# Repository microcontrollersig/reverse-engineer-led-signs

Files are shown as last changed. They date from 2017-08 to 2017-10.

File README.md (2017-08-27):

# Figuring out how a commerical Led signs work

#### Images
https://github.com/microcontrollersig/reverse-engineer-led-signs/blob/master/images/readme.md

#### LED matrix(5 columns, 7rows, 14-pins)
http://www.kingbrightusa.com/images/catalog/SPEC/TA20-11EWA.pdf

#### 74HC245
http://www.mouser.com/ds/2/149/MM74HC245A-71310.pdf
http://www.ti.com/lit/ds/symlink/sn74hc245.pdf

#### 74HC373
http://www.st.com/content/ccc/resource/technical/document/datasheet/group1/96/71/e4/bd/17/76/4e/c7/CD00000305/files/CD00000305.pdf/jcr:content/translations/en.CD0000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
http://www.ti.com/lit/ds/symlink/cd74hc373.pdf

#### ULN2003A
https://www.onsemi.com/pub/Collateral/MC1413-D.PDF
http://www.tij.co.jp/jp/lit/ds/slrs027o/slrs027o.pdf

#### 74HC237B
http://www.ti.com/lit/ds/symlink/cd74hc237.pdf

# Files in Repository
Main one is **ledmatrixmodule.fzz** . You need to install **Fritzing** to view it (schematic view). If you can't be stuffed, open **ledmatrixmodule_schem.pdf**

# Things Learned
1. Rows in the first half of the board are connected, rows in the second half are connected,
   but rows in first half are not connected to the second.
2. Rows get their data from output of 3-8 demux (74HC237), the three inputs of demux are connected to input connector
3. Columns get their data from the latches (74HC373), inputs of which are connected to input connector.
4. Row scanning occurs, the darlington array (ULN2003) inverts its inputs, result being that one line will be LOW, the rest HIGH
   at any point.
5. There are 2 ULN2003A. Output of 1 ULN2003A connected to the rows in the first half,
   the other ULN2003A connected to rows in second half.
6. Corresponding inputs of both ULN2003A are connected.

# Interesting Pictures

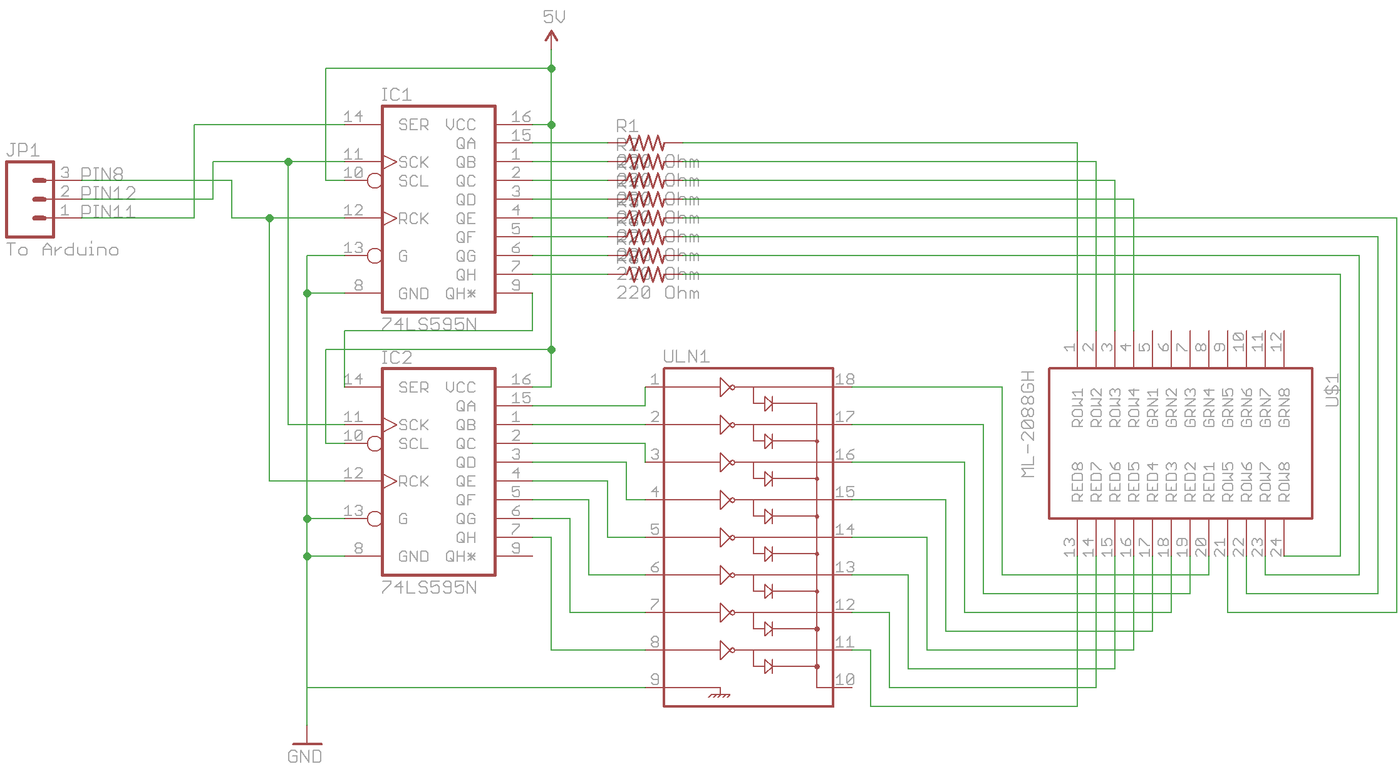
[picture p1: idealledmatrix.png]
Ideal LED matrix design


Similar design

Nice one

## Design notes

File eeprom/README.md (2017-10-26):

# Adventures with 8031

#### Files

This file was the one recovered from EEPROM using programmer
https://github.com/microcontrollersig/reverse-engineer-led-signs/raw/master/eeprom/eepromseansign.bin

This file is the disassembly using mcu8051ide
https://github.com/microcontrollersig/reverse-engineer-led-signs/blob/master/eeprom/eepromseansign.asm

This is also a disassembly, but with actual locations in EEPROM and opcodes
https://github.com/microcontrollersig/reverse-engineer-led-signs/blob/master/eeprom/eepromseansignlst.asm

This file is the intel hex equivalent needed for emu8051
https://github.com/microcontrollersig/reverse-engineer-led-signs/raw/master/eeprom/eepromseansign.hex

#### Tools
A fool with a tool is still a fool!

Used the following using Ubuntu:

* emu8051
* mcu8051ide

On Windows:

* HxD best hex editor
* Windows 10 calculator in Programmer mode great for conversion between dec/hex/binary 

mcu8051ide is hardcore, emu8051 is lean and nifty.

#### References
* http://www.keil.com/support/man/docs/is51/is51_opcodes.htm
* http://www.8052.com/tutsfr.php
* http://www.edsim51.com/8051Notes/8051/memory.html

#### Progress
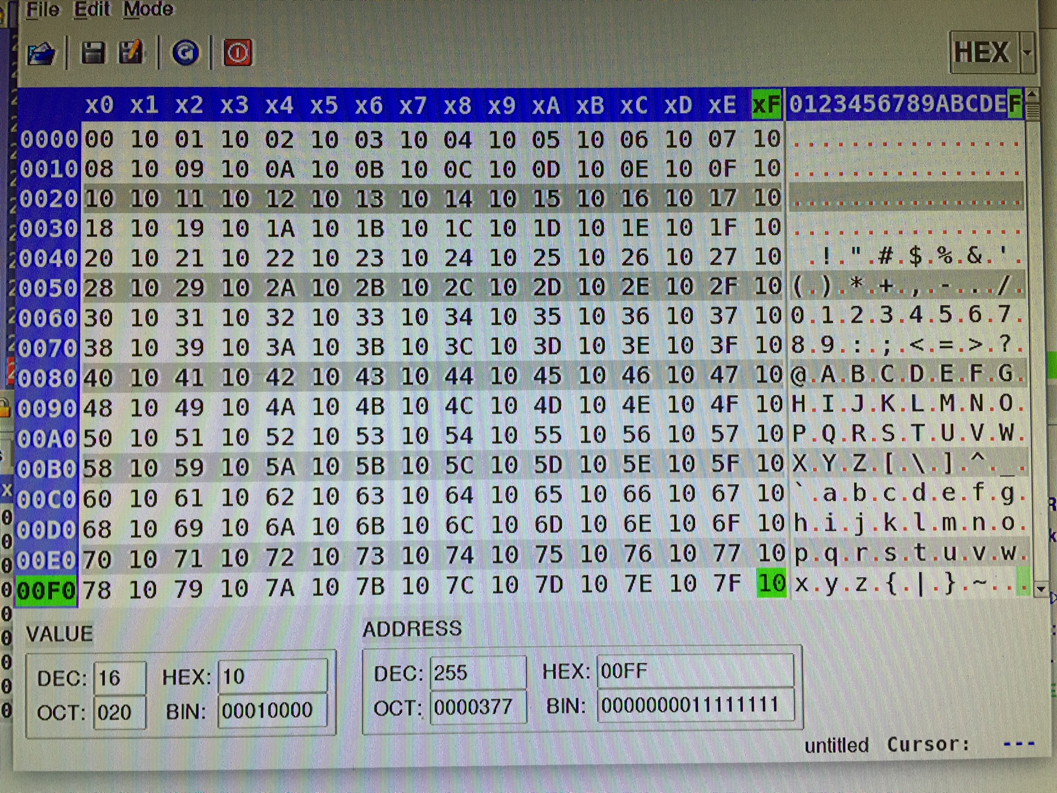
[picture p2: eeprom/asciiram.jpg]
ascii 8051


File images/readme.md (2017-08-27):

# Images (click on the image to rotate it properly!)

#### Component side LEDM1-LEDM3
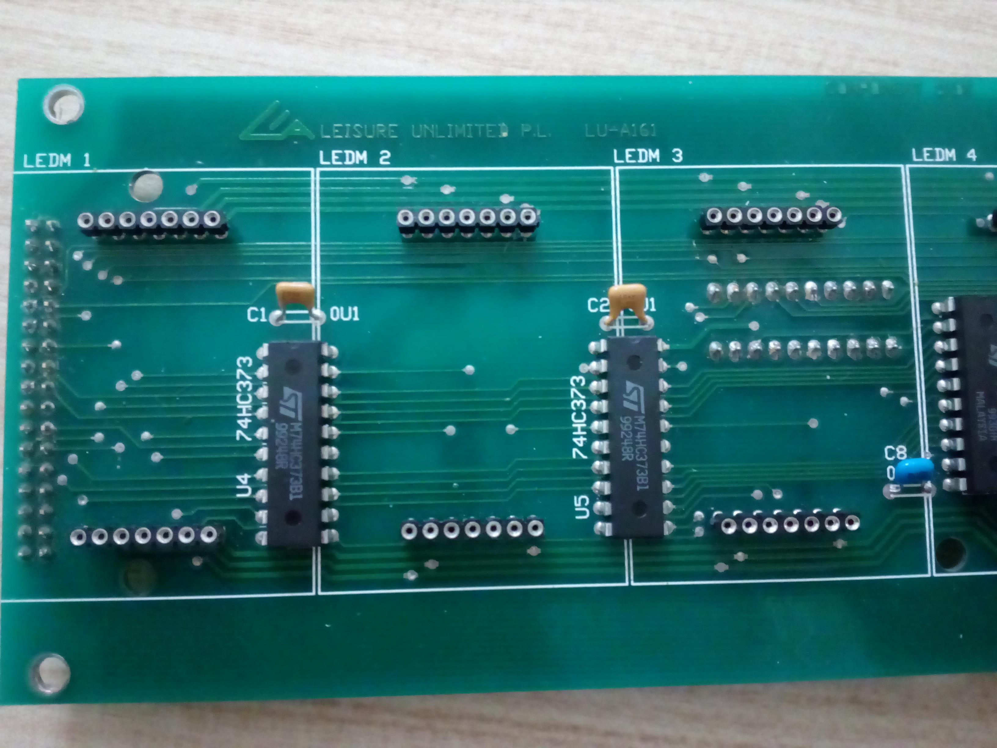
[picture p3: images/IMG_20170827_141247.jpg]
LEDM1-LEDM3


#### Component side LEDM3-LEDM4
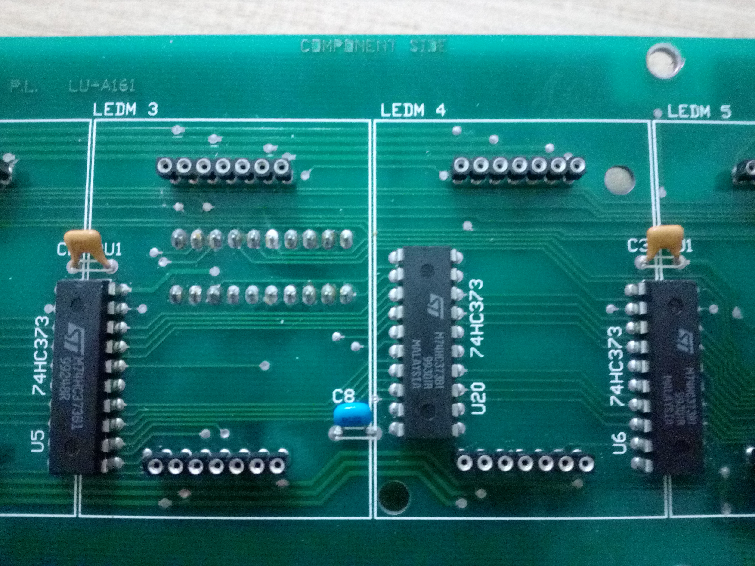
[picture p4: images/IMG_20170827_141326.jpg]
LEDM3-LEDM4


#### Component side LEDM4-LEDM5
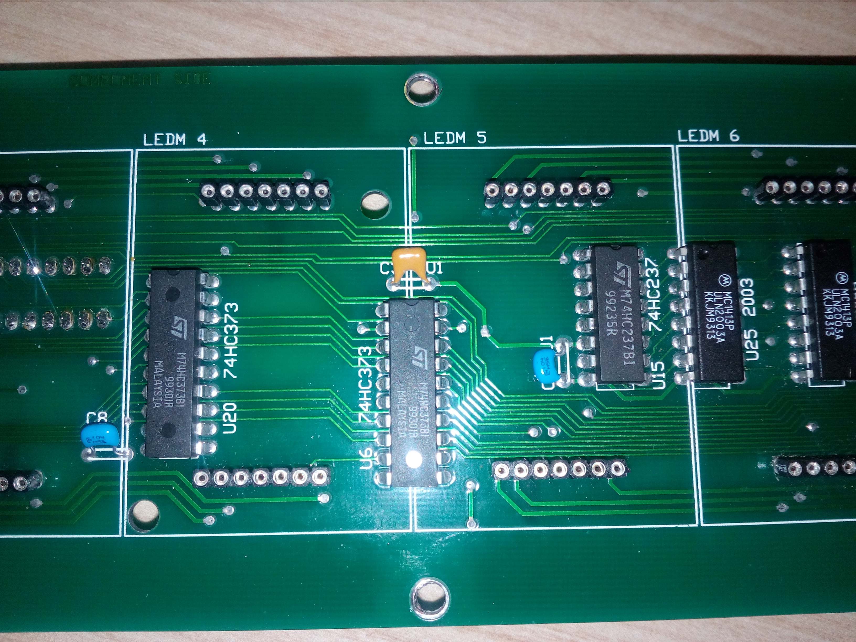
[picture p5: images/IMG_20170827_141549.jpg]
LEDM4-LEDM5


#### Component side LEDM4-LEDM6
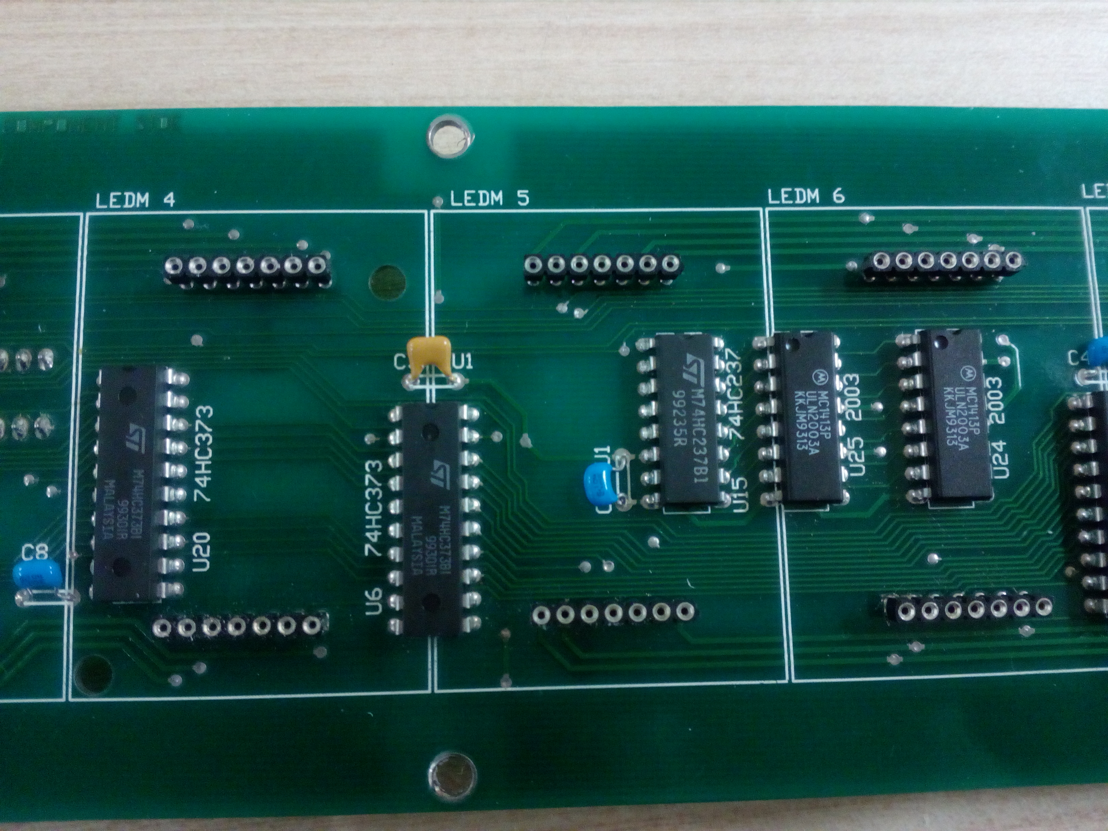
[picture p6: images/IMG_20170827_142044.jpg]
LEDM4-LEDM6


#### Componenet side LEDM7-LEDM8
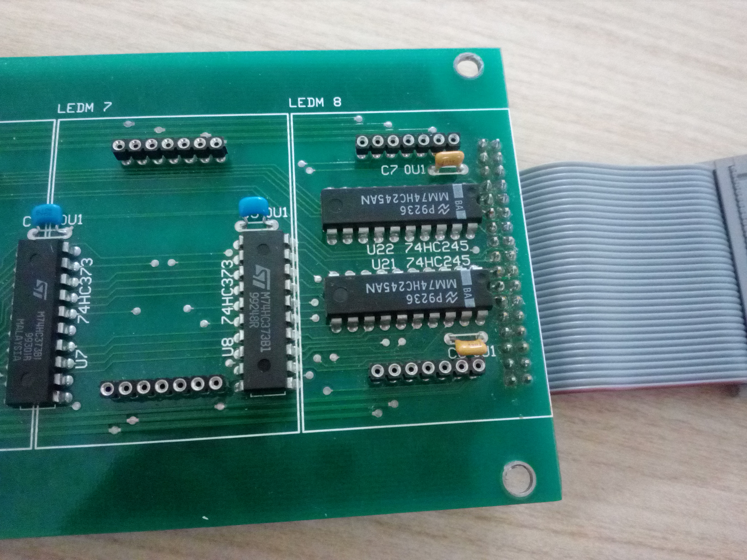
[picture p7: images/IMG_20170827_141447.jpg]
LEDM7-LEDM8


#### Component side
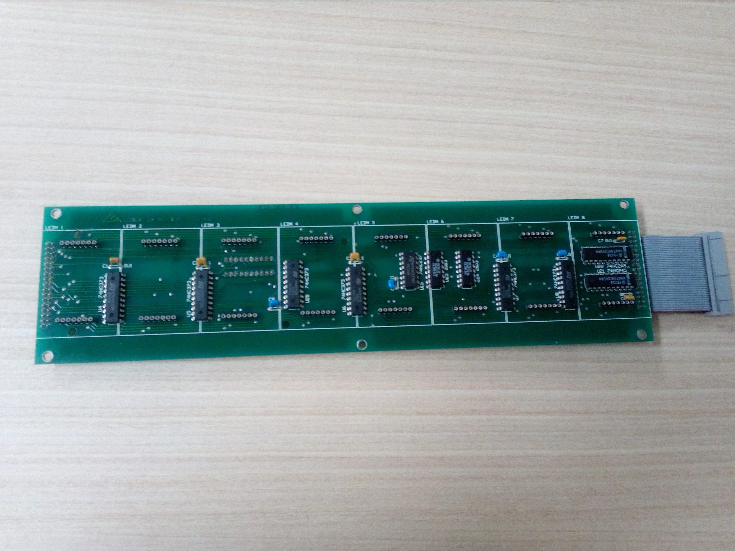
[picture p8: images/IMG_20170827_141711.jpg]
Component side


#### Bottom side
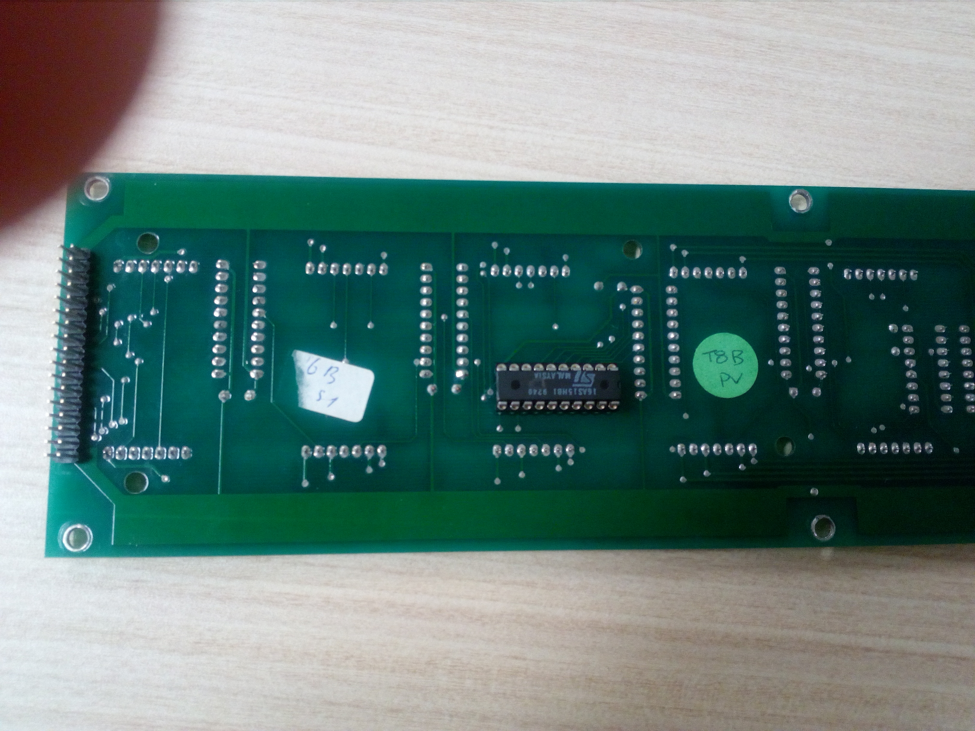
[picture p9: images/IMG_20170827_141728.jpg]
Bottom side


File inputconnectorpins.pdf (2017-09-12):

Sheet1

INPUT CONNECTOR PIN (HEADER SIDE/ bottom side, follow IDE numbering pin1 is 5V)
PIN | COMPONENT | COMPONENT PIN | LED
1 | 5V
2 | 5V
3 | 5V
4 | 5V
5 | 5V
6 | 5V
7 | 5V
8 | 5V
9
10
11 | 74HC373(U4) | 18(D7) | pin11(C3)
12 | 74HC373(U4) | 17(D6) | pin10(C4)
13 | 74HC373(U4) | 14(D5) | pin6(C5)
14 | 74HC373(U4) | 13(D4) | pin13(C1)
15 | 74HC373(U4) | 8(D3) | pin3(C2)
16 | 74HC373(U4) | 7(D2) | pin11(C3)
17 | 74HC373(U4) | 4(D1) | pin10(C4)
18 | 74HC373(U4) | 3(D0) | pin6(C5)
19 | 74HC245(U22) | 12(B7)
20
21 | 74HC237(U15) | 2(A1)
22
23 | 74HC245(U22) | 16(B3)
24 | 74HC245(U22) | 15(B4)
25 | 74HC237(U15) | 3(A3)
26 | 74HC237(U15) | 1(A0) | 1st of 3 pins used to select row to be lit up (scanned)
27 | GND
28 | GND
29 | GND
30 | GND
31 | GND
32 | GND
33 | GND
34 | GND

2

nd of 3 pins used to select row to be lit up (scanned)

3

rd pin of 3 pins used to select row to be lit up (scanned)

Sheet1

ROLE

D7->Q7->LED_PIN11(J9)
D6->Q6->LED_PIN10(J9)
D5->Q5->LED_PIN6(J3)
D4->Q4->LED_PIN_13(J2)
D3->Q3->LED_PIN3(J1)
D2->Q2->LED_PIN_11(J2)
D1->Q1->LED_PIN_10(J2)
D0->Q0->LED_PIN_6(J1)
goes to GAL

1st of 3 pins used to select row to be lit up (scanned)

2

nd of 3 pins used to select row to be lit up (scanned)

3

rd pin of 3 pins used to select row to be lit up (scanned)

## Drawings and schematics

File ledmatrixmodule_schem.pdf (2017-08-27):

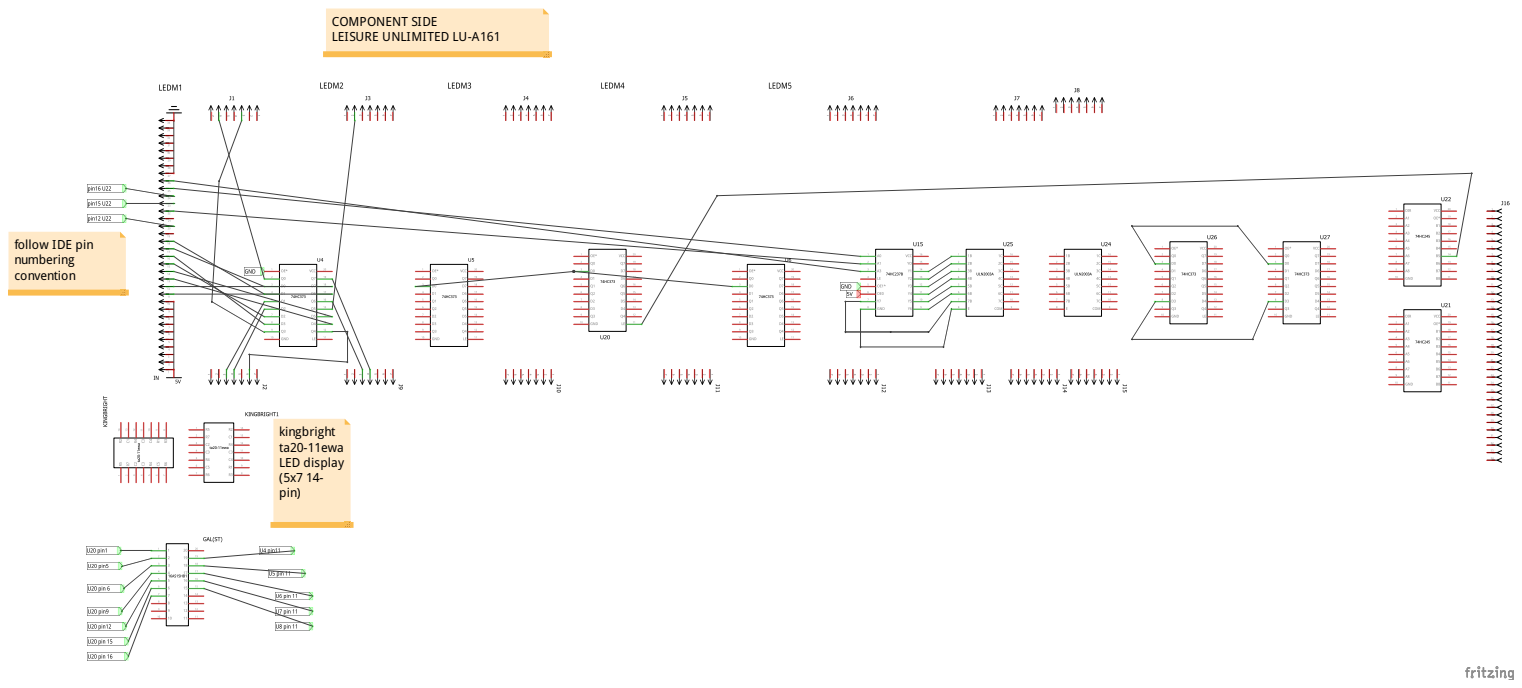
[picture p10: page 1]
kingbright ta20-11ewa LED display (5x7 14- pin)

COMPONENT SIDE
LEISURE UNLIMITED LU-A161

follow IDE pin
numbering
convention

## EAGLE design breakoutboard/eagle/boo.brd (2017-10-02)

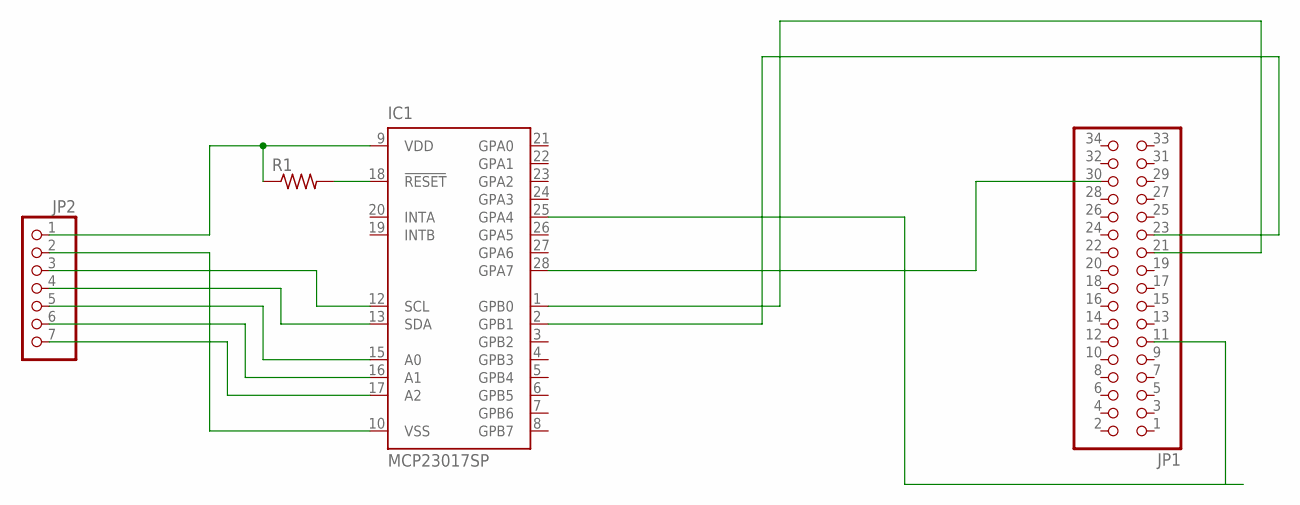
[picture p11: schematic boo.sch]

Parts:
IC1: MCP23017SP; DIL28-3
JP1: PINHD-2X17; 2X17
JP2: PINHD-1X7; 1X07
R1: R-US_0207/10; 0207/10

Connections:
unnamed: IC1.1 (GPB0), JP1.21
unnamed: IC1.2 (GPB1), JP1.23
unnamed: IC1.9 (VDD), JP2.1, R1.1
unnamed: IC1.10 (VSS), JP2.2
unnamed: IC1.12 (SCL), JP2.3
unnamed: IC1.13 (SDA), JP2.4
unnamed: IC1.15 (A0), JP2.5
unnamed: IC1.17 (A2), JP2.7
unnamed: IC1.18 (!RESET), R1.2
unnamed: IC1.28 (GPA7), JP1.30
unnamed: IC1.25 (GPA4), JP1.11

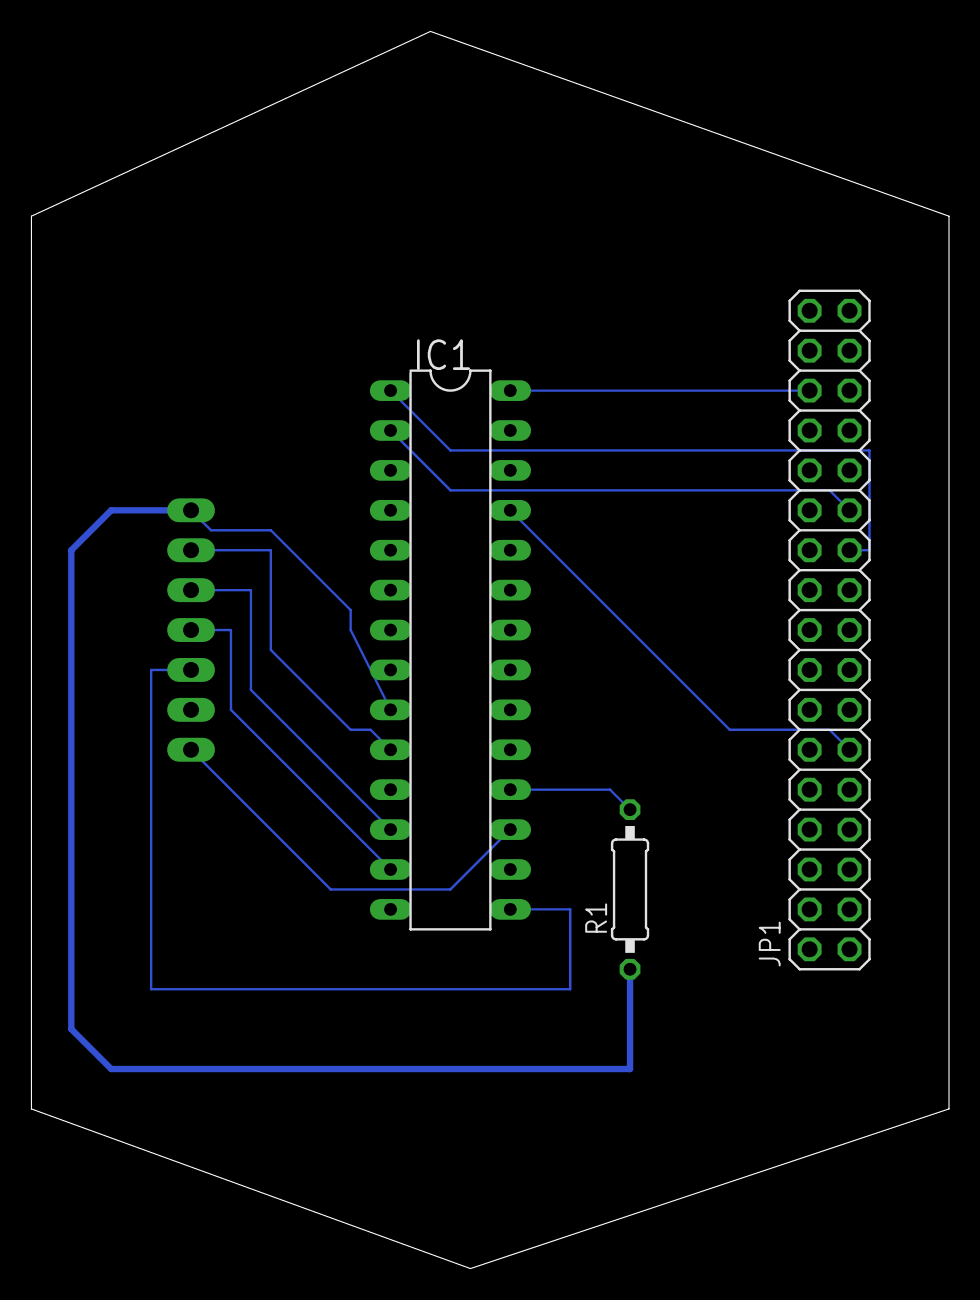
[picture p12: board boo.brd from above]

Board: 2 copper layers, 58.4 x 78.7 mm, 4 parts (1 on the bottom side), 11 nets.
